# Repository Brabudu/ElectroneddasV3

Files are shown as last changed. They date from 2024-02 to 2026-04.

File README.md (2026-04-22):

# ELECTRONEDDAS V3.0

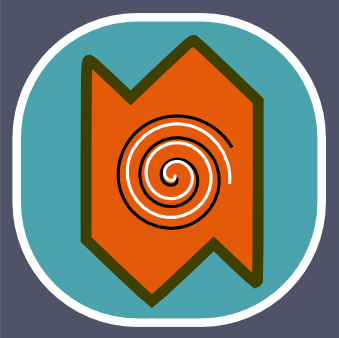
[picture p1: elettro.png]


[Il sito pubblico](https://electroneddas.altervista.org)

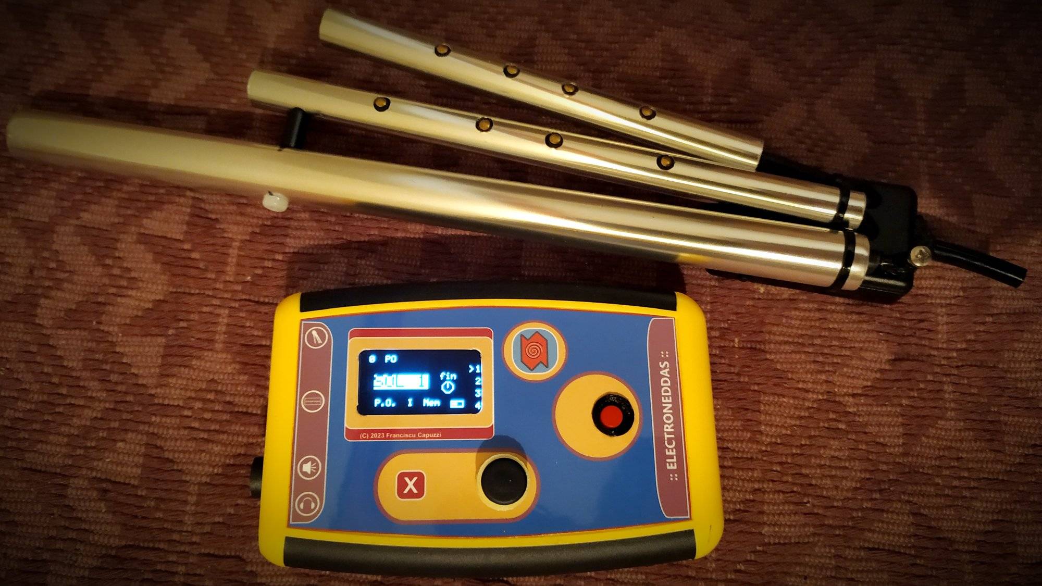
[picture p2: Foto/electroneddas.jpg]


Il terzo modello delle Electroneddas è opensource!

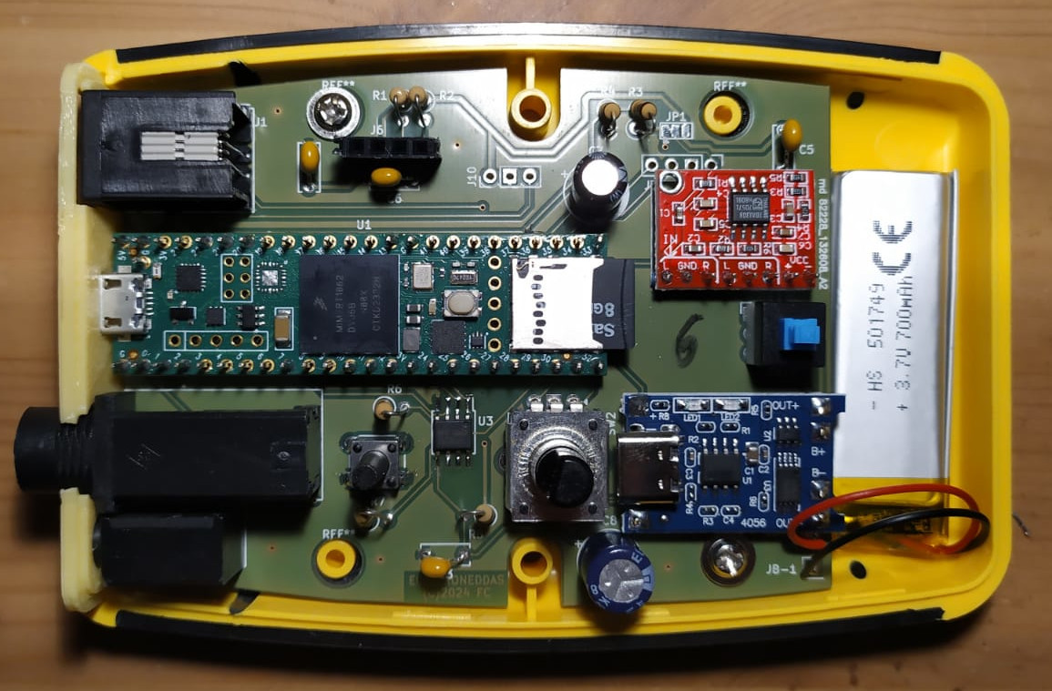
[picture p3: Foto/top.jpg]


## Teensy_Electroneddas:
  Contiene il codice da caricare sul Teensy 4.1 (modalità 396mhz Usb audio+serial+midi)
  
  La compilazione richiede le librerie ArduinoJson e GiverOled 
  
## Java_Electroneddas:

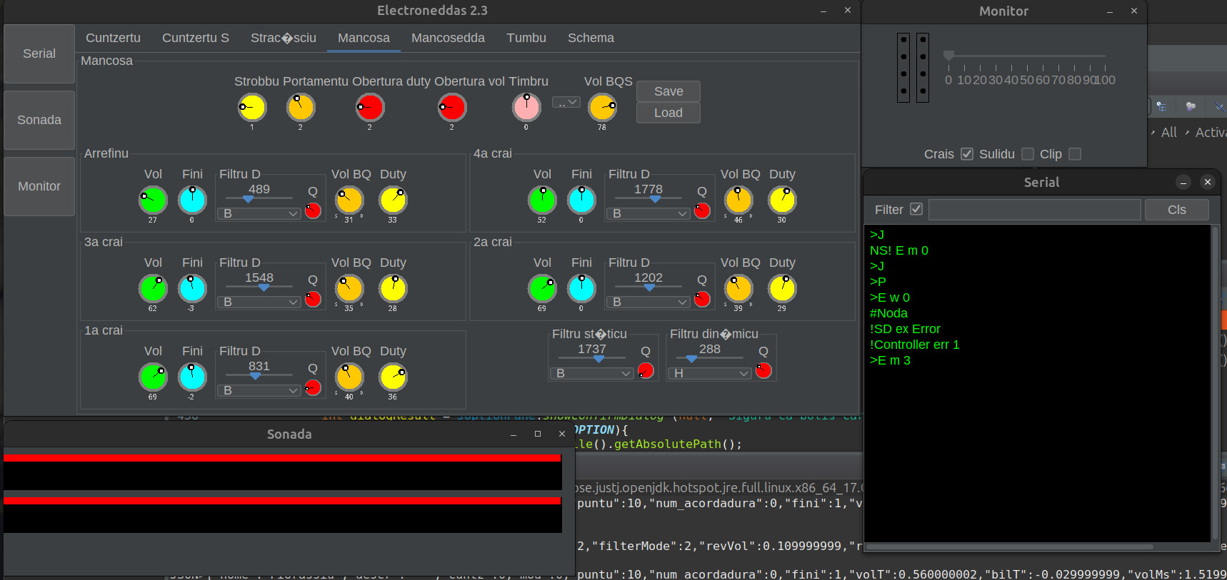
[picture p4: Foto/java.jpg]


  Contiene il codice java per generare il jar dell'applicazione di controllo

## Electronic_Electroneddas:
  Contiene i file kicad con lo schema e il pcb del sintetizzatore e del controller

## 3D_Electroneddas:

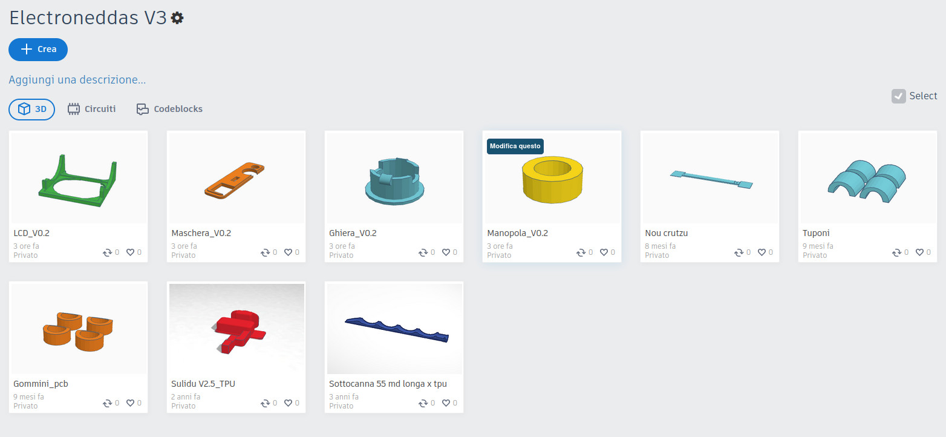
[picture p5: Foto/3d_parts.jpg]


  Contiene i file per le parti da stampare in 3d

## Microchip_Electroneddas:
  Contiene i file per la programmazione del PIC del controller

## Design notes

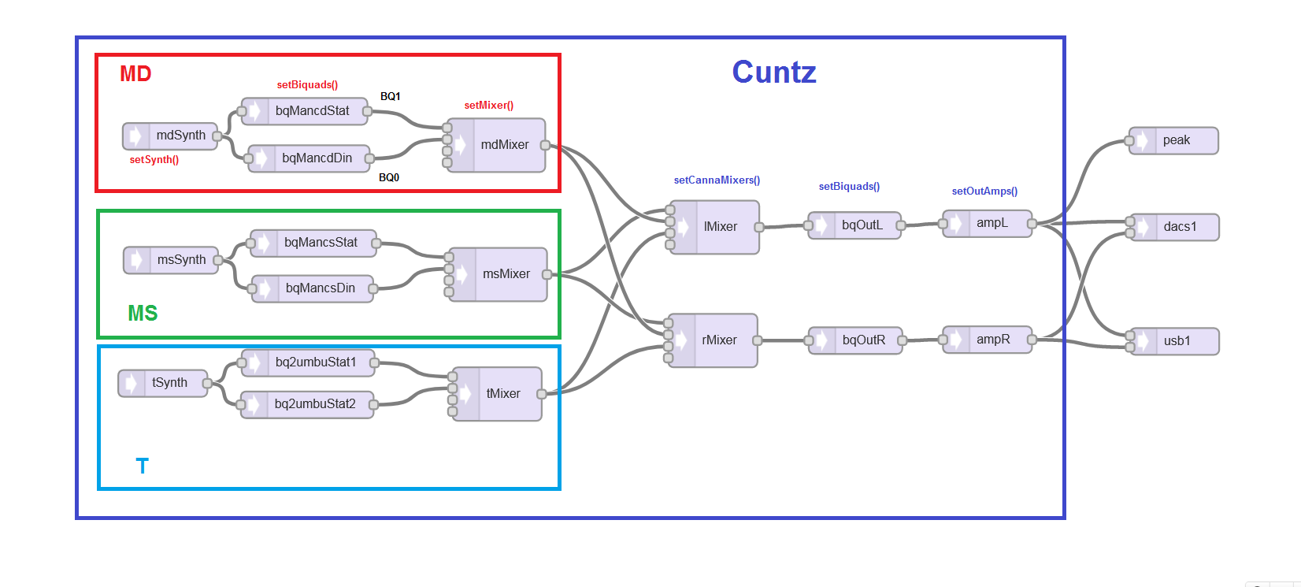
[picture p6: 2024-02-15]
Java_Electroneddas/Electroneddas/src/img/Schema4b.png

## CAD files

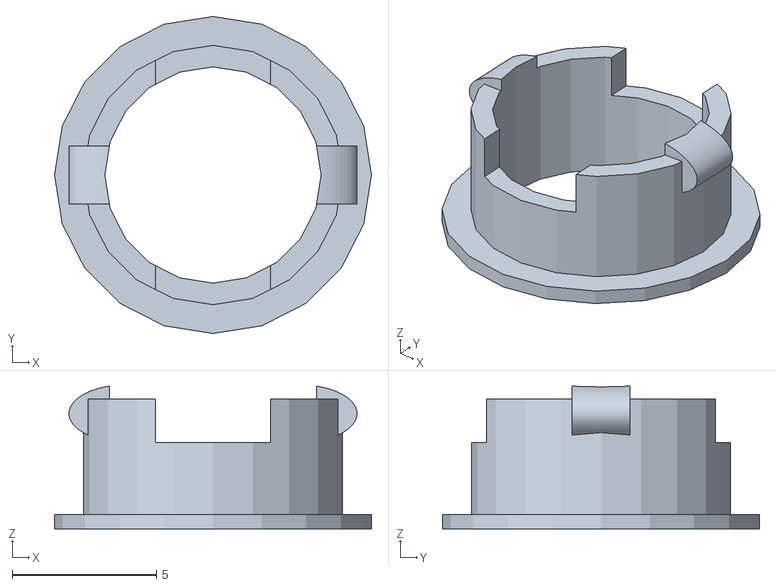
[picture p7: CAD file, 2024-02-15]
3D_Electroneddas/Synth/Ghiera_V0.2.stl
11.0 x 11.0 x 4.95

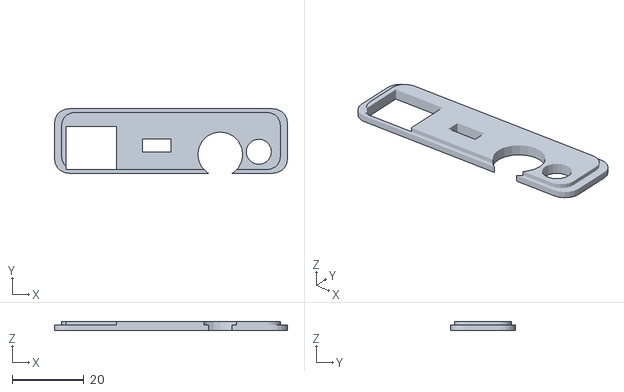
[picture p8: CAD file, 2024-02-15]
3D_Electroneddas/Synth/Maschera_V0.2.stl
65.0 x 18.0 x 2.60

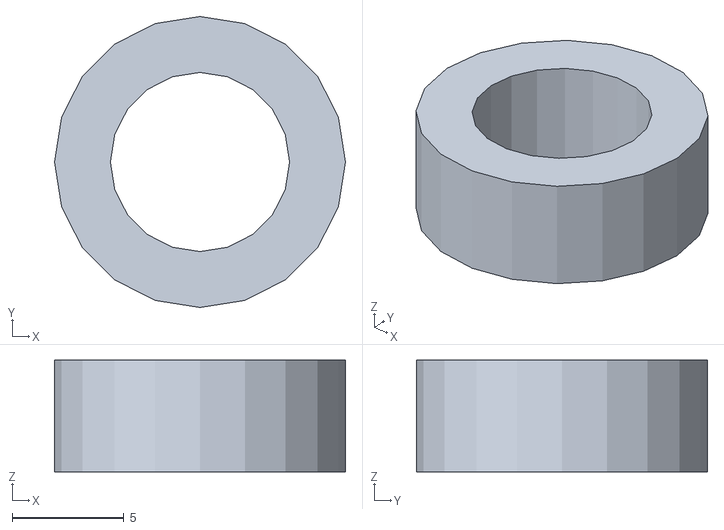
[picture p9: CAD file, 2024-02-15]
3D_Electroneddas/Synth/Manopola_V0.2.stl
13.0 x 13.0 x 5.00

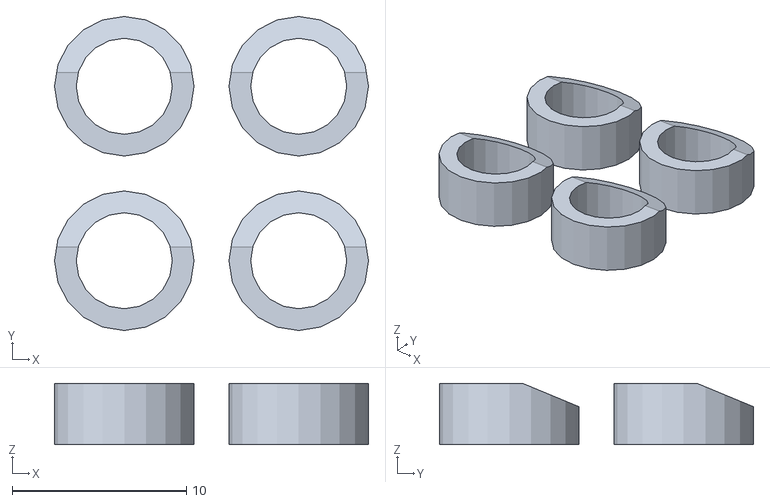
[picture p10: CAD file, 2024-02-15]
3D_Electroneddas/Synth/Gommini_pcb.stl
18.0 x 18.0 x 3.50

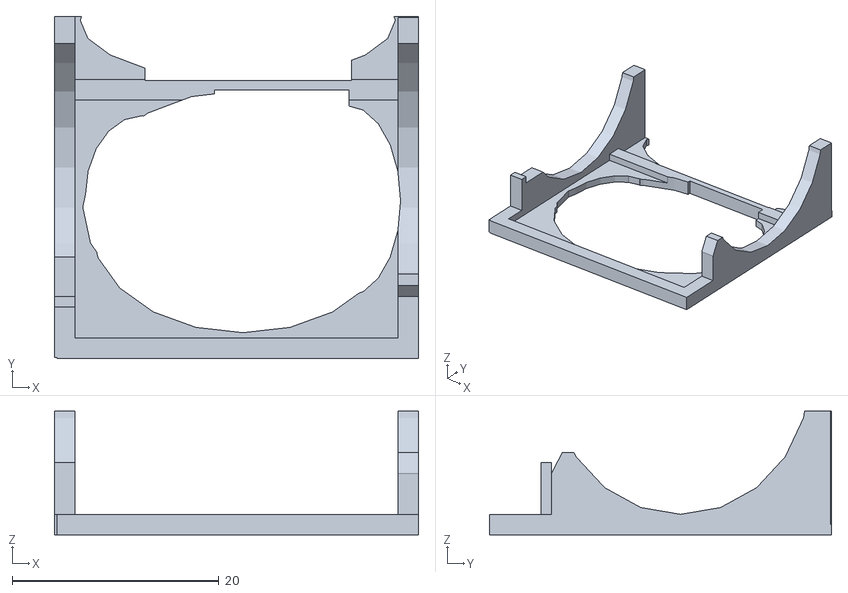
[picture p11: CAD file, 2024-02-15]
3D_Electroneddas/Synth/LCD_V0.2.stl
35.2 x 33.1 x 12.0

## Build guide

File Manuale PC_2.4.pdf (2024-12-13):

Manuale applicazione PC, V2.4

# Pagina iniziale

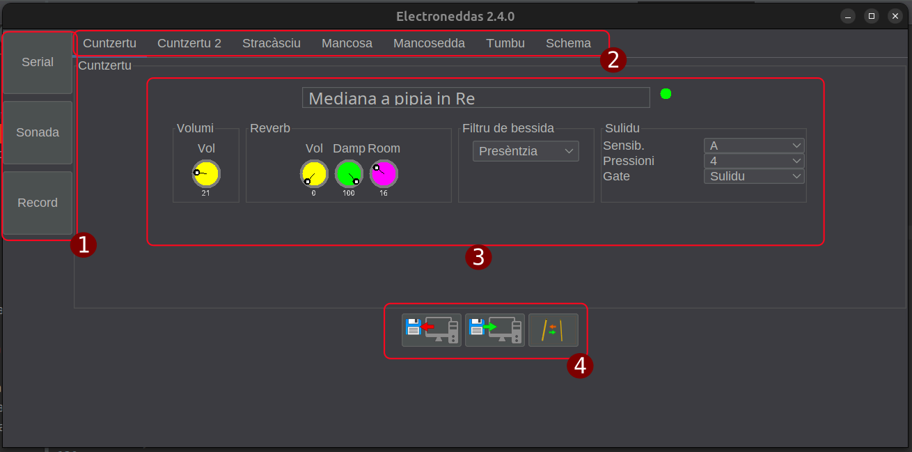
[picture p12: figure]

# ① Bottoni per finestre secondarie

### Ogni bottone fa apparire una finestra secondaria. Le finestre sono descritte più

avanti.

Serial: Visualizza la comunicazione fra PC e electroneddas

Sonada: Visualizza la finestra con la suonata in tempo reale

Record: Visualizza la finestra relativa alla registrazione

# ② Selezione del pannello di lavoro

Cliccando su un bottone viene visualizzata una scheda nella zona ③.

Ogni scheda viene descritta in seguito nel presente manuale.

Cuntzertu: Gestisce le impostazioni generali

Cuntzertu 2: Gestisce le impostazioni relative al cuntzertu attualmente in uso

Stracàsciu: Gestisce is stracàscius dello strumento

Mancosa - Mancosedda - Tumbu : Visualizza le impostazioni della canna

Schema: Visualizza lo schema generale dello strumento

# ③ Pannello di lavoro ④ Operazioni sul cuntzertu

1) Salva cuntzertu: Salva su PC il cuntzertu attuale (* spesso è più utile salvare tutto lo

stracàsciu, vedi oltre)
2) Carica cuntzertu: Carica dal PC il cuntzertu attuale (* meglio lavorare sullo stracàsciu,

vedi oltre)
3) Scambia canne: Scambia le impostazioni relative a timbro e accordatura di mancosa e

mancosedda.
NB! Le canne vengono scambiate completamente solo se è selezionato il tipo di cuntzertu “Personali” (vedi “Cuntzertu 2”). In caso contrario le note delle canne rimangono quelle relative al cuntzertu attuale e non vengono scambiate.

# Cuntzertu

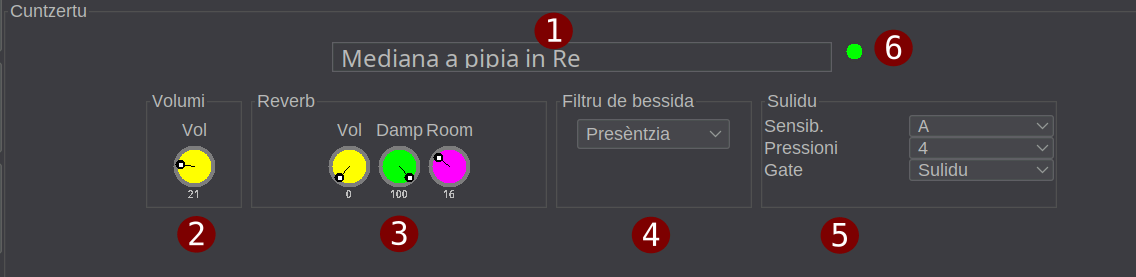
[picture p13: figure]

Questo pannello contiene delle impostazioni raggiungibili anche tramite il display delle electroneddas:

# ① Nome cuntzertu ② Volume generale ③ Effetto riverbero ④ Filtro di uscita ⑤ Impostazioni fiato ⑥ Spia di clipping

Se il monitoraggio del clipping è attivo (vedi “Sonada”), la spia diventa rossa quando i volumi delle canne superano il valore massimo gestibile dallo strumento col pericolo di produrre un suono distorto.
In tal caso conviene abbassare leggermente i volumi delle canne e salvare nuovamente su cuntzertu

# Cuntzertu 2

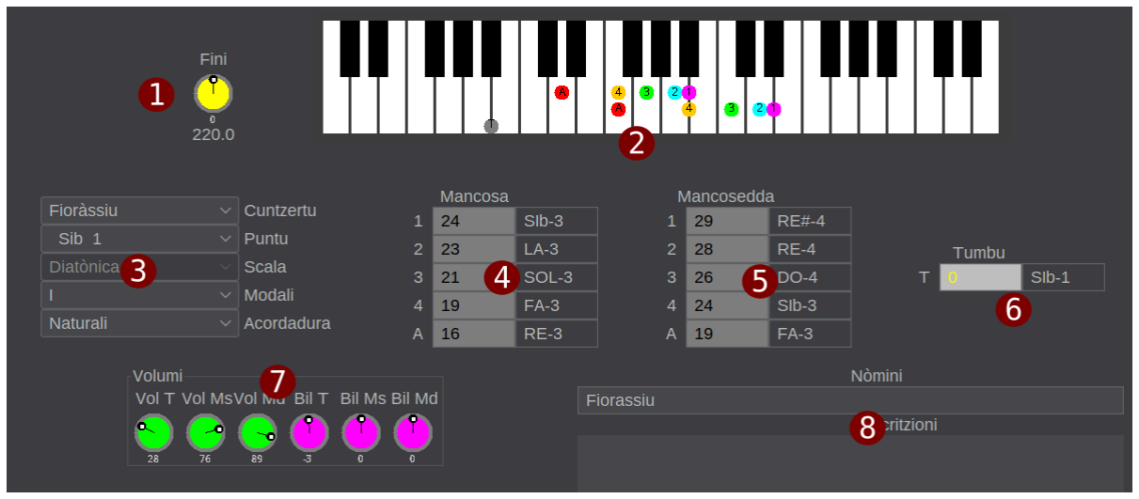
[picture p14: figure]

# ① Accordatura fine dello strumento ② Disposizione de is crais (sola lettura)

Il pannello mostra quali sarebbero le note del tumbu (La T in basso), della mancosa (in alto) e

della mancosedda (a metà) sulla tastiera del pianoforte.

# ③ Impostazioni generali dello strumento

Cuntzertu: Il menu a tendina permette di scegliere un tipo di cuntzertu esistente oppure

di crearne uno personalizzato (selezionando *personali, vedi 4 e 5)
Puntu: Permette di scegliere la tonalità dello strumento

Scala: Permette di scegliere su quale scala viene costruito lo strumento

Modali: Permette di scegliere il grado della scala su cui viene costruito lo strumento. Gli

strumenti tradizionali in genere utilizzano il primo grado della scala (I)
Acordadura: Imposta l’accordatura generale de is crais de su cuntzertu. La nota finale

de is crais dipenderà anche dall’accordatura fine dello strumento e delle singole crais

# ④ ⑤ ⑥ Note di mancosa, mancosedda e tumbu

Le tabelle mostrano il numero di semitoni a partire dalla tonalità di base dello strumento. I valori non possono essere modificati a meno che non sia stato selezionato lo strumento *personali (vedi 3-Cuntzertu)

# ⑦ Pannello volume e bilanciamento

Le manopole verdi permettono di modificare il volume delle tre canne, mentre quelle magenta permettono di spostare il suono della canna verso il canale destro o sinistro (solo per l’uscita stereofonica)

# ⑧ Nome e descrizione strumento

Qui è possibile modificare il nome e la descrizione de su cuntzertu che poi appariranno nel display o nel pannello de su stracàsciu

# Stracàsciu

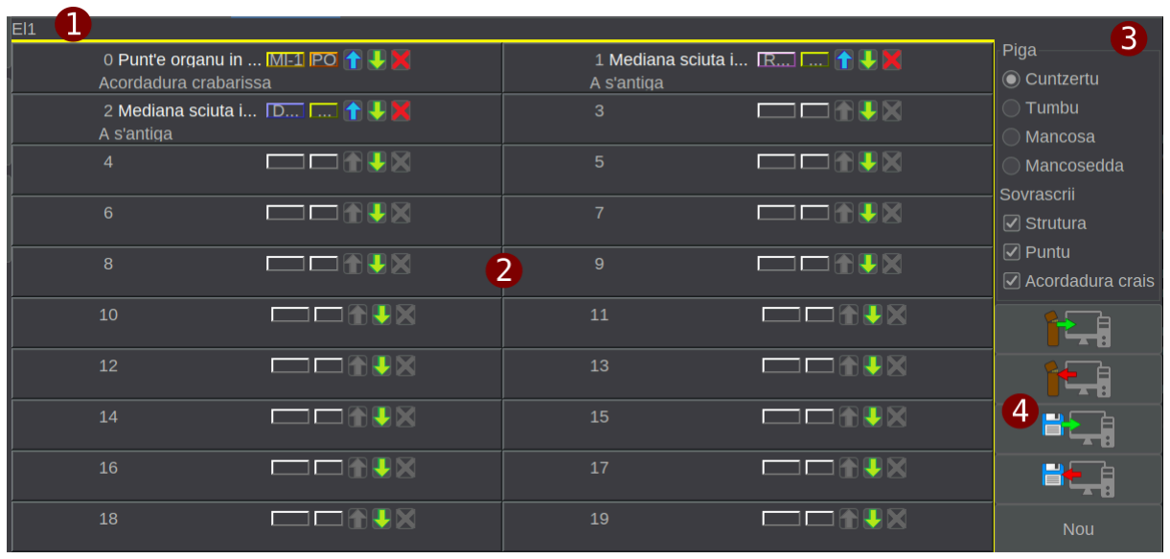
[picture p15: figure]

Su stracàsciu rappresenta un gruppo di strumenti su cui lavorare.
Unu stracàsciu può contenere al massimo 20 strumenti.

### Tale stracàsciu è memorizzato temporaneamente nel PC, per cui la memoria dello strumento non viene modificata a meno che lo stracàsciu non venga poi salvato

nelle electroneddas (vedi oltre).

### Lo stracàsciu di appartenenza di uno strumento memorizzato nelle electroneddas dipende dal suo numero. I primi 20 strumenti (da 0 a 19) apparteranno allo

stracàsciu 0, quelli da 20 a 39 allo stracàsciu 1 e così via.

# ① Nome de su stracàsciu

Se su stracàsciu è stato caricato dalle elettroneddas avrà un nome del tipo El* in cui * indica il numero dello stracàsciu. El0 ad esempio sarà lo stracàsciu di base con gli strumenti dal numero 0 al numero 19, El1 il secondo sctracàsciu con strumenti dal 20 al 39 etc.
Gli stracàsciu caricati dal disco prenderanno invece il nome del file corrispondente

# ② Pannello de is cuntzertus

Ogni riga rappresenta unu cuntzertu. La riga è spiegata nel dettaglio più avanti.

NB Se lo stracàsciu proviene dalle electroneddas, il numero effettivo de su cuntzertu dipende dal numero dello stracàsciu attuale

# ③ Opzioni

Piga: Permette di scegliere se l’operazione piga prenderà interamente o solo in parte unu

cuntzertu dallo stracàsciu (per l’operazione piga (prendi) vedi oltre)
Cuntzertu prende tutto lo strumento, tumbu solo il tumbu e così via.
NB a meno che il cuntzertu non sia di tipo “personali”, le note delle canne rimarranno bloccate al tipo di cuntzertu attualmente in uso, ma verranno prese solo le accordature fini, i volumi, i filtri etc.
Sovrascrii: Permette di scegliere se l’operazione poni salverà interamente lo strumento

nello stracàsciu oppure solo parzialmente:
Strutura: sovrascrive anche le note de is crais dello strumento
Puntu: sovrascrive anche l’intonazione dello strumento
Acordadura de is crais: sovrascrive anche l’intonazione fine de is crais dello strumento
Scala: Permette di scegliere su quale scala viene costruito lo strumento

Modali: Permette di scegliere il grado della scala su cui viene costruito lo strumento. Gli

strumenti tradizionali in genere utilizzano il primo grado della scala (I)
Acordadura: Imposta l’accordatura generale de is crais de su cuntzertu. La nota finale

de is crais dipenderà anche dall’accordatura fine dello strumento e delle singole crais

# ④ Operazioni sullo stracàsciu

Carica unu stracàsciu dalle electroneddas

Salva unu stracàsciu nelle electroneddas

Carica unu stracàsciu dal PC

Salva unu stracàsciu dalle electroneddas

Cancella lo stracàsciu e ne crea unu vuoto

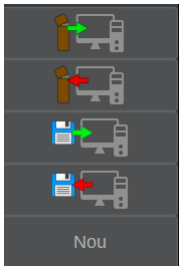
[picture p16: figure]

## NB Solo l’operazione “Salva nelle electroneddas” modifica la memoria dello strumento

# Operazioni su unp strumento de su stracàsciu

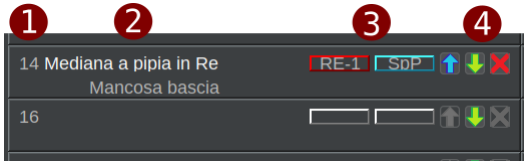
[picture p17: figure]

# ① Numero progressivo dello strumento de su

### stracàsciu (Sola lettura)

# ② Nome e descrizione dello strumento (Sola lettura)

# ③ Tonalità e tipo di cuntzertu dello strumento (Sola

### lettura)

# ④ Operazioni sullo strumento:

Piga (prendi, freccia azzurra) : Prende lo strumento (es. 14) de su stracàsciu. Tale strumento diventa quello correntemente in uso nelle electroneddas, a meno che non si sia fatta una scelta diversa nel riquadro “Piga” (Vedi Opzioni nel paragrafo precedente)

Poni (metti, freccia verde) : Mette lo correntemente in uso nello strumento (es. 14) de su stracàsciu., a meno che non si sia fatta una scelta diversa nel riquadro “Sovrascrii” (Vedi Opzioni nel paragrafo precedente).

Boga (togli, croce rossa): Svuota la riga de su stracàsciu
Es: lo strumento 16 della figura è vuoto

# Mancosa - Mancosedda - Tumbu

## I pannelli “Mancosa” e “Mancosedda” e “Tumbu” permettono di modificare a

fondo il timbro delle canne.
NB Il pannello “tumbu” presenta meno controlli rispetto alle altre canne.

# Caratteristiche generali della canna:

## Strobbu:

Regola la quantità di variazione casuale sulla frequenza della canna. Serve a dare maggior realismo al suono soprattutto in mancanza di modulazione del fiato.

## Portamentu:

Regola la velocità con cui il suono passa da una crai ad un’altra. In altre parole regola l’effetto glissato della canna.

## Obertura duty:

Influisce sul timbro della canna nel caso risulti aperto il tasto subito al di sotto di quello attuale (“crai oberta”). Più precisamente il parametro agisce sul duty cycle dell’onda generata

## Obertura vol:

Influisce sul volume della canna nel caso risulti aperto il tasto subito al di sotto di quello attuale (“crai oberta”).

## Timbru:

Regola collettivamente is crais della canna aprendo o chiudendo il timbro (agisce sul duty cycle dell’onda)

## (Menu a tendina):

Influisce sul timbro della canna scegliendo il tipo di onda generata a monte. (...) P sono onde sintetizzate mentre C sono campionate (utili principalmente po su tumbu)

## Vol BQS:

Influisce sul timbro della canna dando maggior peso al filtro statico o a quello dinamico (vedi sotto).

## Save e load:

Permettono di salvare su file o di caricare da file i dati della canna

## Filtru stàticu:

Imposta le caratteristiche del filtro che viene applicato al suono della canna a prescindere dalla crai suonata (per questo detto statico).

## Filtru dinàmicu:

Il filtro dinamico è composto di due stadi: il primo varia le caratteristiche a seconda del tasto (crai) diteggiato (vedi oltre, Filtro D).
Il secondo stadio, controllato dal riquadro a destra nella figura in alto, è invece unico per tutta la canna.

In qualsiasi tipo di filtro, la sbarra orizzontale indica la frequenza, il menu a tendina il tipo di filtro (L= passa basso, B= passa banda, H= passa alto, l= esalta bassi, h= esalta alti, N= nessun filtro), Q indica il fattore di qualità del filtro, ossia la sua incisività

# Caratteristiche di ogni crai:

## Vol:

Volume relativo de sa crai

## Fini:

Accordatura fine de sa crai

## Filtru D:

Imposta le caratteristiche del primo stadio del filtro dinamico applicato al suono della canna quando risulta aperta tale crai.

## VolBQ

Influisce sul timbro del suono de sa crai dando maggior peso al filtro statico o a quello dinamic).

## Duty

Imposta il duty cycle dell’onda, ossia la larghezza degli impulsi dell’onda rettangolare. In generale un valore basso da un suono più aperto mentre uno alto un suono più chiuso.
Il controllo è ininfluente quando si imposta una forma d’onda campionata (vedi sopra, “menu a tendina”)

# Sonada

# Spartito

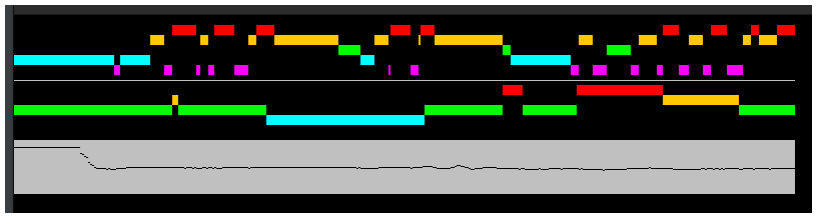
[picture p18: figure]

Questa parte della finestra mostra una trascrizione dinamica dei segnali che arrivano dalle electroneddas.
La parte superiore rappresenta la mancosedda, quella centrale la mancosa e quella inferiore il fiato. (NB I segnali devono essere attivi, vedi sotto)

Cliccando su quest’area della finestra si cambierà la modalità di visualizzazione, a rotazione fra le tre disponibili.

# Situazione sensori

Questa parte visualizza in tempo reale lo stato dei sensori di mancosa e mancosedda. Il foro è giallo se il sensore rileva la presenza del dito. (NB I segnali de is crais devono essere attivi, vedi sotto)

Questa parte visualizza in tempo reale lo stato del sensore di pressione del fiato.
(NB Il segnale de su sulidu deve essere attivo)

# Acquisizione segnali sensori

La casella selezionata indica che il segnale proveniente dalle electroneddas verrà rilevato dal programma. Crais indica i segnali relativi ai tasti, Sulidu al fiato e Clip al raggiungimento del livello di clipping (vedi pannello principale)

# Registrazione su file

Tramite il pulsante indicato tutti i segnali provenienti da is crais verranno salvati su file per potere essere elaborati in seguito per usi particolari. Il programma chiederà di selezionare il nome e la posizione del file e comincerà ad acquisire i dati. L’acquisizione terminerà alla pressione del tasto stop.

# Record

Tramite questo pannello è possibile registrare una sonada per poterla riascoltare in seguito.

# Registrazione e riproduzione

Il tasto Rec avvierà la registrazione, che partirà e si fermerà in base alla modalità di gate selezionata. La registrazione può essere fermata anche col tasto Stop.

Il tasto Play riprodurrà la registrazione presente in memoria. La riproduzione si fermerà al termine della stessa o con la pressione del tasto Stop.

Ogni registrazione cancellerà la precedente, per cui prima di effettuare una nuova registrazione sarà necessario salvarla in memoria.

# Salvataggio in memoria

Per salvarla in memoria occorrerà selezionare prima di tutto la posizione della memoria che si intende utilizzare (da 0 a 100) ed eventualmente il nome che si intende memorizzare (fino a 32 caratteri).
Premendo il tasto Save la registrazione attuale verrà memorizzata permanentemente nella posizione scelta.

Per caricare dalla memoria una registrazione occorre invece scegliere la posizione che si vuole caricare e poi premere il tasto Load.
Se nella posizione scelta esiste una registrazione, il suo nome apparirà nella casellina. In caso contrario apparirà un messaggio di errore.

# Aggiornamento firmware

L’aggiornamento del firmware, cioè del programma che gestisce internamente le electroneddas, va effettuato tramite sistema PC con sistema operativo Windows:

1. Scaricare il file programmatore***.zip (*** indica la versione del file).
2. Scompattare il contenuto dell’archivio in una cartella
3. Collegare le electroneddas al PC tramite USB
4. Accendere le electroneddas
5. Avviare il file program.bat e seguire le indicazioni sullo schermo

# Aggiornamento software

L’aggiornamento del software di controllo da PC descritto in manuale consiste semplicemente nel sostituire il file Electroneddas.jar con la versione più recente

# Problematiche di connessione

Se il PC non dovesse riconoscere le Electroneddas verificare su “Gestione dispositivi” che appaia qualcosa del genere:

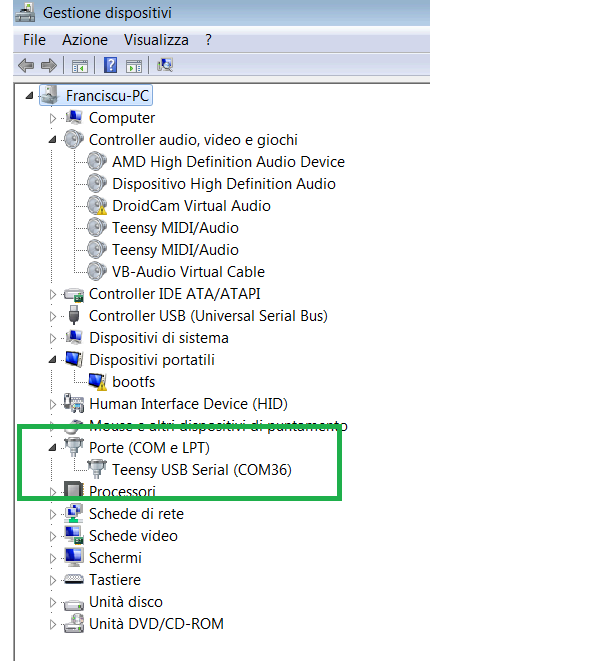
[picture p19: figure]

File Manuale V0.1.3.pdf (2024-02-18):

Le electroneddas

1 sono uno strumento musicale elettronico finalizzato a riprodurre le caratteristiche organologiche dello strumento tradizionale: in altre parole sono costruite in modo che il suonatore possa suonarle con la tecnica il più possibile simile a quella che utilizza sulle launeddas.

# Il controller

Il controller è la parte dello strumento che il suonatore tiene in mano, su cui quindi poggia le dita, e in cui può soffiare per dare espressione alla suonata.
La posizione dei tasti (crais) è fissa, e viene decisa generalmente dal suonatore in base alle proprie preferenze.
I tasti sono del tipo a sfioramento, cioè non richiedono una pressione delle dita, e riconoscono due stati: tasto aperto e tasto chiuso.
Non è quindi possibile effettuare glissati, poiché lo strumento non riconosce l'apertura parziale di un foro.
Il suonatore può soffiare tramite il tubo ①
La vite ② permette di regolare il deflusso di aria; per ottenere un ulteriore deflusso la vite può essere rimossa.

Il pulsante ③ (presente nel nuovo modello) ha due funzioni:

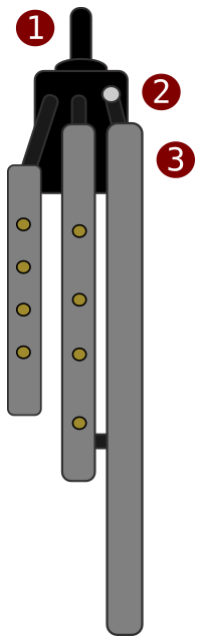
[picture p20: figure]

- Se viene premuto per qualche istante durante la fase di accensione dello strumento, permette di impostare una minore sensibilità dei tasti rispetto al normale
- Mantenendolo premuto durante il normale funzionamento permette di scegliere il cuntzertu precedente o successivo toccando i tasti alti o bassi della mancosa

1
Indifferentemente Eletroneddas (grafia sarda), Elettroneddas (grafia italiana) o Electroneddas

UNA PRESSIONE DI ARIA ECCESSIVA POTREBBE DANNEGGIARE LO STRUMENTO: UTILIZZARE ESCLUSIVAMENTE IL FIATO

La parte relativa al fiato può essere pulita periodicamente inserendo qualche goccia di alcool tramite un contagocce.
I tasti possono essere puliti con un panno asciutto o imbevuto di alcool.

# Il sintetizzatore

Il sintetizzatore contiene i circuiti elettronici che generano il suono e comunica con il controller tramite un cavo (telefonico) e con il PC tramite porta USB. Lo schema sottostante mostra lo schema del cavo.

Il suonatore può scegliere su cuntzertu, la tonalità e tutti gli altri parametri interagendo con il controller tramite lo schermino LCD , la manopola e il tasto presente sul sintetizzatore.

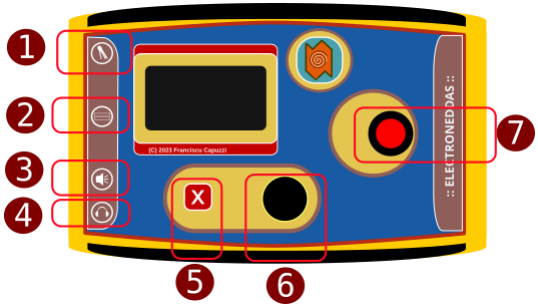
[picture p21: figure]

# ① Ingresso controller (rj 11)

Collegare il controller a strumento spento. Nel caso lo si faccia a strumento acceso, premere ripetutamente il tasto annulla (5) per inizializzare la comunicazione.

# ② Uscita USB / Ricarica (mini usb b)

Utilizzare un cavo mini usb di tipo b per caricare lo strumento e/o comunicare con l’applicazione delle elettroneddas installata su pc o per inviare comandi MIDI al pc

③ Uscita audio (jack 6.3mm mono)

L’uscita è monofonica e non amplificata.

④ Uscita cuffie (jack 3.5mm stereo)

L’uscita è stereofonica e amplificata. Prima di indossare le cuffie controllare che il volume non sia troppo alto

# ⑤ Tasto annulla ⑥ Rotella selezione

Muovendo la rotella si cambia pagina o si controlla il cursore all’interno del display, premendola è possibile selezionare o modificare i parametri (vedi dopo)

# ⑦ Pulsante accensione e spia ricarica

Una luce rossa attorno al pulsante indica che la batteria è in carica, una luce blu che la carica ha raggiunto il massimo

# Pagina 1

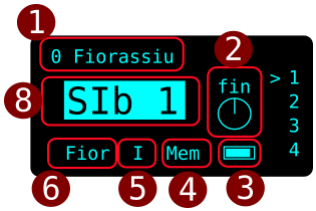
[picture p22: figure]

# ① Strumento selezionato ② Accordatura fine ③ Livello batteria ④ Memorizza strumento

Premendo la rotellina per oltre un secondo vengono memorizzate le regolazioni dello strumento attuale (quelle della pagina 1 e della pagina 2)

# ⑤ Scala modale ⑥ Tipo cuntzertu

# Pagina 2

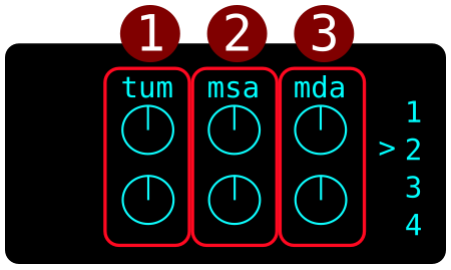
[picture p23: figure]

# ① Volume/bilanciamento tumbu ② Volume/bilanciamento mancosa ③ Volume/bilanciamento mancosedda

NB Il bilanciamento ha effetto solo sull’uscita stereofonica

# Pagina 3

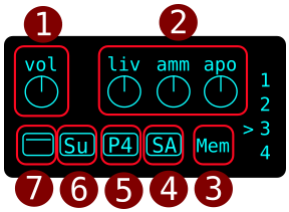
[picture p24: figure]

# ① Volume uscita

Regola il volume di uscita dello strumento. Un valore troppo alto potrebbe dare distorsione

### ② Riverbero: livello, attenuazione, stanza

Il livello (liv) regola la quantità di riverbero rispetto al suono pulito, attenuazione (amm) l’effetto sulle alte frequenze (damping) mentre stanza (apo) indica la dimensione della stanza simulata

# ③ Memorizza

Premendo la rotellina per oltre un secondo vengono memorizzate le regolazioni di questa pagina

# ④ Sensibilità fiato

Tre livelli: Alta (SA), media (SM) e bassa (SB)

# ⑤ Pressione fiato

Cinque livelli: da P0 (bassa) fino a P5 (alta)

# ⑥ Modalità attivazione

No: suono sempre attivo
Cr: il suono rimane finchè risulta chiuso almeno un foro
Su: il suono rimane finchè è presente una pressione del fiato
AS: il suono si attiva e si disattiva dando un leggero colpo di fiato
CS: modalità Cr e Su combinate ma separate per mancosa e mancosedda

# ⑦ Filtro uscita

￣￣ : nessun filtro
￣\ : attenua le frequenze alte _/￣ : esalta le frequenze alte

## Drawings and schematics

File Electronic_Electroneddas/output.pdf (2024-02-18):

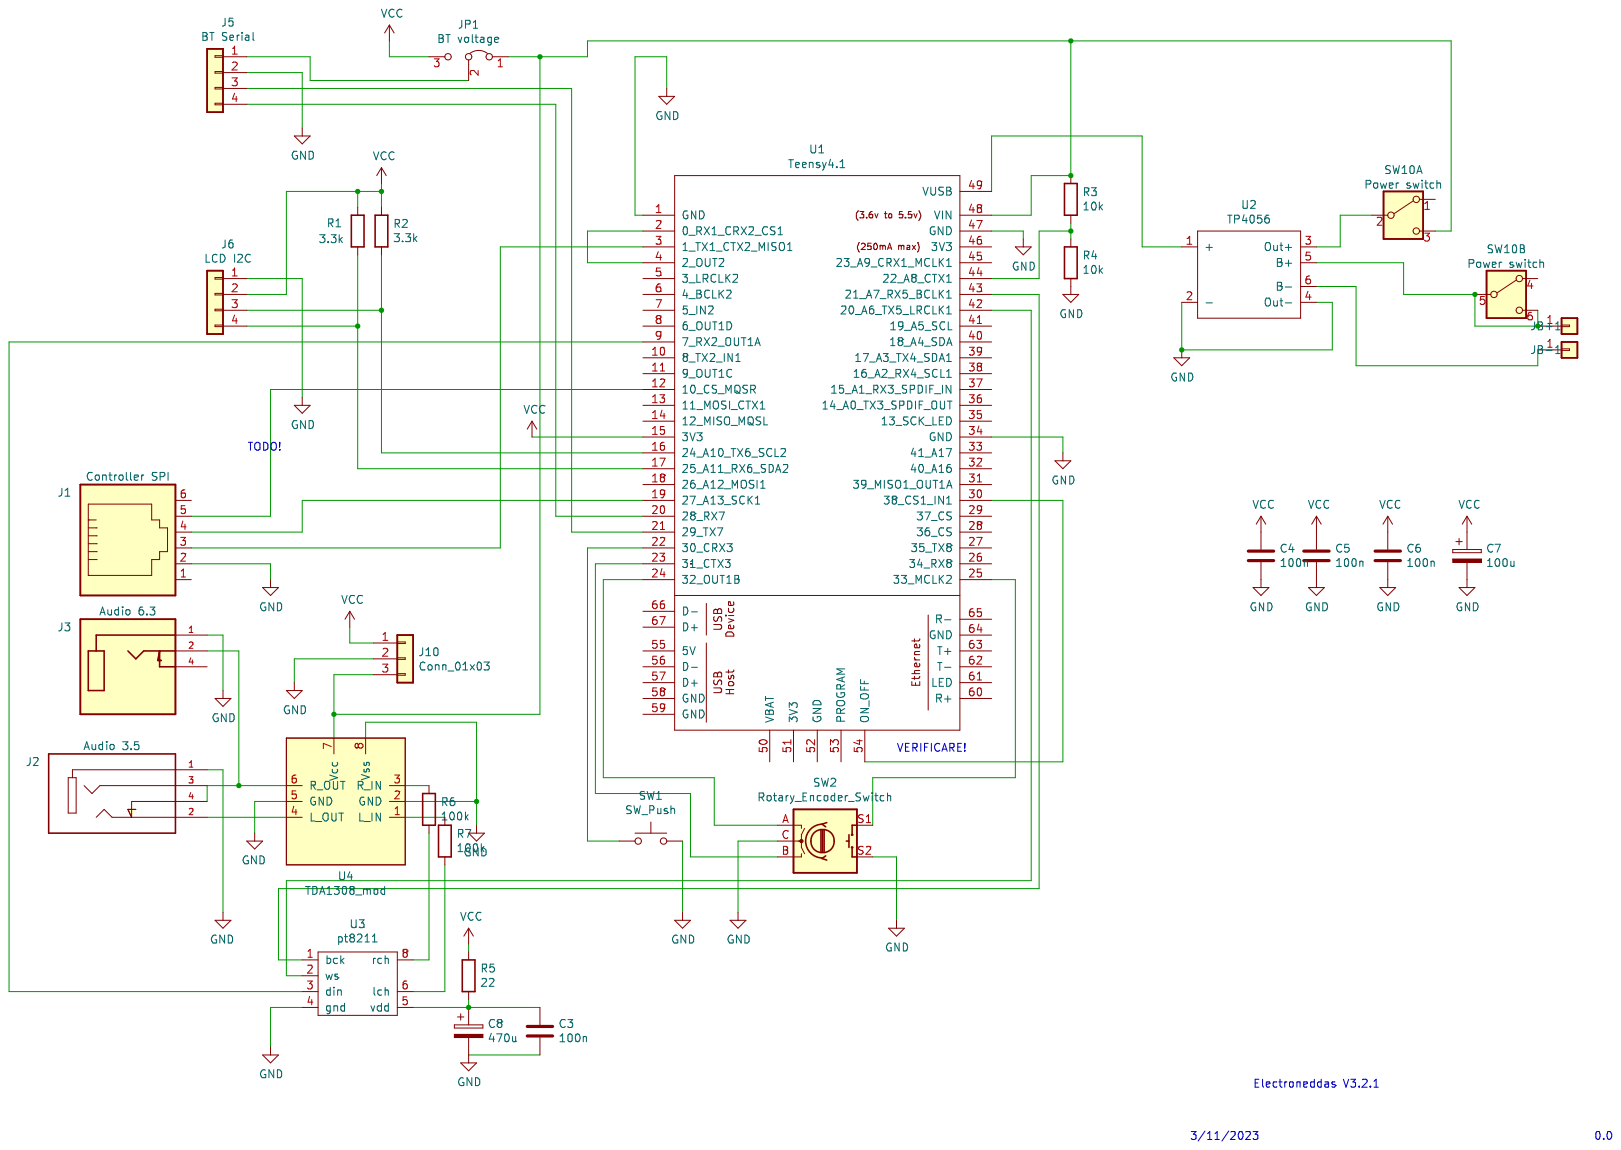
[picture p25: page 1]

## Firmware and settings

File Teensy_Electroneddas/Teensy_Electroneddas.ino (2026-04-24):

/*
Required libraries: 

ArduinoJSON 
  https://arduinojson.org/

GyverOLED
  https://github.com/GyverLibs/GyverOLED


*/

#include <Audio.h>
#include <SPI.h>
#include <ArduinoJson.h>
#include <EEPROM.h>
#include <SerialFlash.h>


#include "Cannas.h"
#include "Display.h"
#include "ElFileSystem.h"

#include "Recorder.h"

#ifndef functions_h
  #include "functions.h"
#endif

#ifndef info_h
  #include "info.h"
#endif

#include "Communicator.h"

#include "2SPISlave_T4/2SPISlave_T4.h"

#include <Entropy.h>

#include "sdios.h"

#define version "2.5.0"

//2.2   12/01/2024  

/*16/4/21
  */

//2.3.1 10/3/24 note negative

//2.3.1 4/4/24 transp midi

const char json[] = "{\"nome\":\"PO\",\"descr\":\"Sol\",\"vol\":0.5,\"cuntz\":1,\"mod\":0,\"puntu\":7,\"fini\":1.0,\"volT\":0.62,\"bilT\":-0.03,\"volMs\":0.98,\"bilMs\":0.0,\"volMd\":1.16,\"bilMd\":0.0,\"bq\":{\"freq\":0,\"q\":0.0,\"type\":\"N\"},\"tumbu\":{\"volArm\":0.9,\"strb\":6,\"sonu\":4,\"port\":10,\"bqStat\":{\"freq\":169,\"q\":1.678804,\"type\":\"H\"},\"bqDinF\":{\"freq\":0,\"q\":0.0,\"type\":\"N\"},\"crais\":[{\"vol\":1.0,\"volA\":1.0,\"fini\":1.0,\"duty\":0.05,\"puntu\":0,\"bq\":{\"freq\":301,\"q\":1.0,\"type\":\"N\"}}]},\"mancs\":{\"volArm\":1.56,\"strb\":2,\"sonu\":1,\"port\":10,\"bqStat\":{\"freq\":2089,\"q\":0.34673685,\"type\":\"B\"},\"bqDinF\":{\"freq\":1148,\"q\":0.3019952,\"type\":\"B\"},\"crais\":[{\"vol\":0.39,\"volA\":2.28,\"fini\":1.0,\"duty\":0.33,\"puntu\":7,\"bq\":{\"freq\":549,\"q\":1.0,\"type\":\"B\"}},{\"vol\":0.52,\"volA\":1.84,\"fini\":1.0,\"duty\":0.3,\"puntu\":9,\"bq\":{\"freq\":2137,\"q\":1.0,\"type\":\"B\"}},{\"vol\":0.62,\"volA\":1.4,\"fini\":0.9928057,\"duty\":0.28,\"puntu\":11,\"bq\":{\"freq\":1737,\"q\":1.0,\"type\":\"B\"}},{\"vol\":0.69,\"volA\":1.56,\"fini\":1.0,\"duty\":0.28,\"puntu\":12,\"bq\":{\"freq\":1348,\"q\":1.0,\"type\":\"B\"}},{\"vol\":0.69,\"volA\":1.6,\"fini\":0.99639636,\"duty\":0.33,\"puntu\":14,\"bq\":{\"freq\":933,\"q\":0.52480745,\"type\":\"B\"}}]},\"mancd\":{\"volArm\":1.62,\"strb\":5,\"sonu\":1,\"port\":10,\"bqStat\":{\"freq\":2089,\"q\":0.4365158,\"type\":\"B\"},\"bqDinF\":{\"freq\":1778,\"q\":1.0,\"type\":\"B\"},\"crais\":[{\"vol\":0.52,\"volA\":2.44,\"fini\":1.0,\"duty\":0.34,\"puntu\":12,\"bq\":{\"freq\":630,\"q\":1.0,\"type\":\"B\"}},{\"vol\":0.56,\"volA\":2.72,\"fini\":0.99639636,\"duty\":0.3,\"puntu\":14,\"bq\":{\"freq\":2238,\"q\":1.0,\"type\":\"B\"}},{\"vol\":0.64,\"volA\":1.32,\"fini\":1.0,\"duty\":0.24,\"puntu\":16,\"bq\":{\"freq\":1659,\"q\":0.91201085,\"type\":\"B\"}},{\"vol\":0.63,\"volA\":1.24,\"fini\":1.0036167,\"duty\":0.26,\"puntu\":17,\"bq\":{\"freq\":1584,\"q\":0.45708817,\"type\":\"B\"}},{\"vol\":0.65,\"volA\":1.56,\"fini\":1.0,\"duty\":0.35,\"puntu\":19,\"bq\":{\"freq\":1122,\"q\":0.44157046,\"type\":\"B\"}}]}}";



//Schema V1.0

#include "schema.h"

extern "C" uint32_t set_arm_clock(uint32_t frequency);

#define HI_SPEED  600000000
#define LOW_SPEED  150000000

////// HARDWARE //////////////////////

#define CS_CON  2     //SPI CS
#define OFF_CON  38   //Todo

#define V_CONTR  10   //SPI Vcc

#define BLUETOOTH Serial7

#define MIDI_IN_CHAN 0


SPISlave_T4 <&SPI1, SPI_8_BITS> mySPI; 
;
////
volatile uint8_t lt_pkt[6]; // Buffer ricezione
volatile uint8_t lt_pr = 0; //
volatile uint8_t lt_pp = 0; //


uint8_t last_error = 0;
uint8_t last_error_mem = 0;



volatile long inact_timer = 0; //


////
float old_sul=0;
int sul_count=0;

//byte oldcrai[2];

////// gestione console //////
char ser_buffer[3000];
int ser_b_index = 0;

String command="";

//////
//Battery
  #define BATT  A8   //Todo
    float charge=4.2;
////// gestione Bluetooth //////
#define MAX_BT_BUFF 128
char cstring1[MAX_BT_BUFF];  //!!!!!!!!!!!!!!!!!!!!!!!!
//byte addbuffer[64];
int cindex1 = 0;
bool cpronto1 = false;

bool bt_controller = false;
bool bt_control = false;

const bool BT_CRLF = true;
//////

//Gestione monitor
#define CRAIS 1
#define ESA   2
#define SUL   4
#define BT    8
#define CLIP  16

int mon_mode=0;

//byte act_file=0; // Caricamento cuntzertu

// Timer monitor (clip)
IntervalTimer monitorTimer;

uint8_t cuntz_num=0;
#define MAX_CUNTZ_NUM 200

// Pedaliera
#define STRAC 0
#define CROMA 1
#define CONTROL 2
#define TUMBU_F  3
#define TUMBU_T 4
#define SCRIPT 5

uint8_t ped_mode=0;
uint8_t ped_last=0;
uint8_t ped_strac=0;
///EEPROM

#define EEPROM_ID 0
#define EEPROM_HW 1

#define HW_BT 0xaa


Cuntzertu* c; 

Display* d;

ElFileSystem* efs;

Communicator* com;

Recorder* rec;

void setup() {

  // Pulsantis e led
  pinMode(PIN_PULS_OK, INPUT_PULLUP);
  pinMode(PIN_PULS_CANC, INPUT_PULLUP);

  pinMode(OFF_CON, OUTPUT);
  digitalWrite(OFF_CON, HIGH);

  pinMode(V_CONTR, OUTPUT);
  
  
  pinMode(LED_BUILTIN, OUTPUT);
  
  // SPI slave
  pinMode(CS_CON, OUTPUT); //CS
  digitalWrite(CS_CON, LOW);

  AudioMemory(20);
  Entropy.Initialize();

  Serial.begin(115200);   //USB
  
  set_arm_clock(LOW_SPEED);

  com=new Communicator(&Serial);

  //Bluetooth
  BLUETOOTH.begin(9600);    //BTooth

  if (EEPROM.read(EEPROM_HW) == HW_BT) {
    bt_control=true;
  }
  
  //BLUETOOTH.addMemoryForRead(addbuffer,64);  // Per comunicare con la app

  digitalWrite(V_CONTR, HIGH);
  delay(100);
  digitalWrite(CS_CON,HIGH);
  
  delay(100);
 
  lMixer.gain(3,0.3);
  rMixer.gain(3,0.3);

  //mdMixer.gain(2,0.7);  //TEST
  //ldMancd.frequency(500);
  //ldMancd.resonance(1);
   
  mySPI.onReceive(receiving);
  mySPI.begin();

  c=new Cuntzertu();

  d=new Display(bt_control);

  efs=new ElFileSystem();
  
  if (!efs->isMounted()) {
        com->msgError("SD Error");
        d->showLogo("SD ERR");
    } else {
        d->showLogo(version);
    }
  initCuntz();
 
  monitorTimer.begin(monitoring, 200000);
  monitorTimer.priority(255);
  
  digitalWrite(V_CONTR, HIGH);

  delay(500);
  digitalWrite(CS_CON,LOW);
  
  if (digitalRead(PIN_PULS_OK)==false) d->test();
  else d->initMenu();

  rec=new Recorder();

   usbMIDI.setHandleProgramChange(myProgramChange);

}

void loop() {

  if (!rec->isPlaying()) {
  
    //USB Serial
    pollSerial();
    
    //BT Serial
    pollBT();
    
    //SPI
    pollSPI();

    pollMIDI();
    

    if (command.length()>0) {
      parse(command);
      command="";
    }
  } else {
    uint8_t s;
    if ((s=rec->getSample())!=0) {
      sona(s);
    }
    //USB Serial
    pollSerial();
  }
}

void pollSerial() {
   while (Serial.available() > 0) 
  {
    inact_timer = 0;
    
    char byteBuffer = Serial.read();  
    ser_buffer[ser_b_index++] = byteBuffer;

    if (ser_b_index>=3000) {
      com->msgError("Serial buffer full");
      ser_b_index=0;
    }
    
    if (byteBuffer == 10)
    {
      ser_buffer[--ser_b_index] = 0;        
      parse(ser_buffer);  //Generali
      
      ser_b_index = 0;
    }
  }
}

void pollSPI() {
    if (lt_pr != lt_pp) {
      inact_timer = 0;
      
      lt_pp++;
      uint8_t b = lt_pkt[lt_pp % 6];
    sona(b);
 
  } 

}
void pollBT() {
 
  if (bt_control) {
  //Bluetooth
    while ((BLUETOOTH.available() > 0) && (!cpronto1))
    {
      char byteBuffer = BLUETOOTH.read();
    
      if (!((cindex1==0)&&((byteBuffer==' ')||(byteBuffer==0)))) { //trim   
         
        cstring1[cindex1++] = byteBuffer;
        if ((byteBuffer == 10)||(cindex1>=MAX_BT_BUFF))
        {
          cstring1[--cindex1] = 0;
  
          if ((mon_mode&BT)||bt_controller) {     
            com->msgInfo("BT> ",cstring1);
          }
          
          if (!bt_controller)  parse(cstring1);  //Generali
       
          cindex1 = 0;
          cpronto1 = false;
        }
      }
    }
  }
}
void pollMIDI() {
  while(usbMIDI.read()){}
}
void sona(uint8_t b) {  

      //Sulidu
      if (b>=128 ) {
        b&=0x7F;
        float sul=(float)b;
      
        if (sul!=old_sul) {
          c->setSul(b);   
          if (rec->isRecording()) rec->putSample(b|0x80); 
          if (mon_mode&SUL) {
            com->msgWarning('s'+String(b),true);
          }
          old_sul=b;
        }
        return;
      }

      //Crais & msg
      if (rec->isRecording()) rec->putSample(b);
      uint8_t canna = 0;
      uint8_t nota = 0;

      uint8_t hi_nibb=b&0xf0;
      uint8_t lo_nibb=b&0x0f;

      if (hi_nibb==0x70) { //Comando da controller
        int dir=0;
        if (lo_nibb==0) return;
        if (b&0x1) dir=1;
        if (b&0x8) dir=-1;

        if (!efs->isMounted()) return;
        do {
          cuntz_num=(cuntz_num+dir+MAX_CUNTZ_NUM)%MAX_CUNTZ_NUM;
        } while (!efs->cuntzFromFileJson(c,cuntz_num,true));
        c->setPreferredCuntz(cuntz_num);
        d->displayPage();
        d->update();
      
      } else {
        nota = byteToCrai(b, &canna);
               
        if (mon_mode&CRAIS)  {
          String can;
         
          if (canna==1) can="S"; 
          else can="D";
          
            String msg=can+":";
            char myHex[2] = "";
   
            if (mon_mode&ESA) ltoa(lo_nibb,myHex,16);
            else ltoa(nota,myHex,16);
            msg+=String(myHex);
            com->msgWarning(msg,true);
              
        }
       
        if (canna == 1) {
          c->mancs.playCrai(nota,lo_nibb);
        }
        if (canna == 2) {
          c->mancd.playCrai(nota,lo_nibb);
        }


        if (canna == 3) {           //Sys msg
          if (b==3) {
            last_error=0;   //Controller prontu (0x33)
            last_error_mem=0;
            com->msgOk("Controller prontu");
          }
          else {
            last_error=1+(b>>1);
            last_error_mem=last_error;
          }
        }
      }
}

void monitoring() {
  if ((mon_mode&CLIP)&&peak.available()) {    
    uint8_t lPeak=peak.read() * 100.0;
    if (lPeak>99) com->msgWarning("CLIP",false);
  }
  
  if (last_error!=0) {
    String msg="Controller err "+String(last_error);
    com->msgError(msg);
    last_error=0;
  }

  //Batteria
  int v=analogRead(BATT);
  float volt=v/155.152; //(v=x/1024*3,3*2);
  charge=(charge+volt)/2; //max=0,7

  d->refreshBattery();
  
  inact_timer++;

  if (inact_timer>2000) {
    //digitalWrite(OFF_CON,LOW);
    //delay(5000);
  }
  
}
float getCharge() {
  return charge;
}
uint8_t byteToCrai(uint8_t b, uint8_t* msg) {

  *msg = ((b >> 4) & 0x3) ^ 3;
  if ((b & 0x80) == 0x80) *msg = 0;

  b = ~b & 0xf;// & ~(c.cannas[*msg - 1].mask & 0xf);

  if (b & 8) return (4);
  if (b & 4) return (3);
  if (b & 2) return (2);
  if (b & 1) return (1);
  return (0);
}



void receiving() {

  if (mySPI.active()) {
    mySPI.pushr(0);
    uint16_t data = mySPI.popr();
    lt_pr++;
    lt_pkt[lt_pr % 6] = (uint8_t)data;    
  }
}
void parse(String s) {
  s.trim();
  if (s.length()==0) return;
  if (s[0]!='E') {
    c->parse(s); //Cuntzertu
  }
  else {
    String sParams[5];
    StringSplit(s, ' ', sParams, 5);
    switch (sParams[1][0]) {
      case 'i':
        com->msgInfo(String("Id :")+EEPROM.read(0));
        com->msgInfo(String("Hw :")+EEPROM.read(1));
        com->msgInfo(String("Version :")+version);
        com->msgInfo(String("Audio memory: ")+AudioMemoryUsageMax());    
        com->msgInfo(String("Audio CPU max: ")+AudioProcessorUsageMax());
        break;
        /* Noise Test
      case 't':
        nMixer.gain(0,sParams[2].toFloat());
        nMixer.gain(1,sParams[3].toFloat());
        break;
      case 'f':
        bqNoise.setHighpass(0,sParams[2].toInt(),1);
        noise1.amplitude(sParams[3].toFloat());
        break;
        */
      case 'I':
        EEPROM.write(EEPROM_ID,sParams[2].toInt()&0xff);
        EEPROM.write(EEPROM_HW,sParams[3].toInt()&0xff);
      break;
      case 'm':
        mon_mode=sParams[2].toInt();
        break;
      case 'B':
        BLUETOOTH.println(sParams[2]);
        BLUETOOTH.flush();
        break;
      case 'b':
        bt_controller=sParams[2].toInt();
        break;
      case 'd':
        efs->listaFiles(false);
        break;
      case 'S':
        set_arm_clock(sParams[2].toInt()*1000000);
        break;
      case 'D':
        efs->listaFiles(true);
        break;
      case 'x':
        efs->deleteFile(sParams[2]);
        break;
      case 'e':
        efs->execute(sParams[2].toInt());
        break;
      case 'n':
        efs->newFile(sParams[2]);
        break;
      case 't':
        efs->torra(sParams[2].toInt());
        break;
      case 'g':
        c->setGateMode(sParams[2].toInt());
        break;
      case 's':
        efs->cuntzToFile(c,sParams[2].toInt());
        break;
      case 'l':
        efs->cuntzFromFileJson(c,sParams[2].toInt(),true);
        break;
      /*case 'L':
        ldMancd.frequency(sParams[2].toInt());
        ldMancd.resonance(sParams[3].toFloat());
        mdMixer.gain(2,sParams[4].toFloat());  //TEST
        break;
        */
      case 'f':
        //efs->cuntzFromFileFunction(c,sParams[2].toInt(),false);
        efs->cuntzFromFile(c,sParams[2],false,'F');
        break;
      case 'r':
        efs->cuntzFromFileJson(c,sParams[2].toInt(),false);
        break;
      case 'h':
        resetController();
        break;
      case 'z':
        efs->readPrefs(c);
        break;
      case 'p':
        efs->savePrefs(c);
        break;
      case 'c':
        delay(500);
        initCuntz();
        break;
      case 'u':
        d->displayPage();
        d->update();
        break;
      case 'w':
        if (sParams[2].toInt()==0) {
          d->setEnabled(false);        
        } else {
          d->setEnabled(true);        
        }
        break;
      case 'v':   //reverb 
       {
        float d=sParams[2].toInt()/10;
        float r=sParams[3].toInt()/10;
        freeverbR.roomsize(r);
        freeverbR.damping(d);
        freeverbL.roomsize(r);
        freeverbL.damping(d);
       }
      break;
      case 'Y': //restore
        restore();
      break;
      case 'N':
        playNoda();
        break;
      case '?':
        com->msgInfo(info_E);
        break;
      case 'R':
         rec->parse(s); //Cuntzertu
        break;
      case 'P':   //Pedaliera 
      {
          uint8_t ped=sParams[2].toInt();
          switch (ped_mode) {
            case STRAC: {
              if (ped!=7) efs->cuntzFromFileJson(c,sParams[2].toInt()+ped_strac,true);   
               d->displayPage();
               d->update();            
            }
            break;
            case CROMA: {
              if (ped!=7) {
                c->setPuntu(c->getPuntu()-ped_last+ped);
                d->displayPage();
                d->update();
              }
            }
            break;
            case CONTROL: {
              if (ped!=7) {
                switch (ped) {
                  case 0: {
                  if (!efs->isMounted()) break;
                  do {
                    cuntz_num=(cuntz_num+1+MAX_CUNTZ_NUM)%MAX_CUNTZ_NUM;
                    } while (!efs->cuntzFromFileJson(c,cuntz_num,true));
                  }
                  break;
                  case 1: {
                  if (!efs->isMounted()) break;
                  do {
                    cuntz_num=(cuntz_num-1+MAX_CUNTZ_NUM)%MAX_CUNTZ_NUM;
                    } while (!efs->cuntzFromFileJson(c,cuntz_num,true));
                  }
                  break;
                  case 2:
                    c->setPuntu(c->getPuntu()+1);
                  break;
                  case 3:
                    c->setPuntu(c->getPuntu()-1);
                  break;
                  case 4:
                    c->setModal(c->getModal()+1);
                  break;
                  case 5:
                    c->setModal(c->getModal()-1);
                  break;
                  case 6:
                    efs->cuntzFromFileJson(c,cuntz_num,true);                 
                    break;               
                }     
              }          
                d->displayPage();
                d->update();
              
            }
            break;
           
            case TUMBU_F: {
              if (ped!=7) c->parse("T C0 p "+String(c->diatToCroma(ped,c->getModal()))+"\n");
            }
            break;
            case TUMBU_T: {
              if (ped==7) c->parse("T C0 p 0\n");
              else c->parse("T C0 p "+String(c->diatToCroma(ped+1,c->getModal()))+"\n");
            }
            break;
      }
       if (ped!=7) ped_last=ped;
      
      }
      break;
      case 'M':   //Modu pedaliera
         ped_mode=sParams[2].toInt();
         switch (ped_mode) {
          case CROMA:
            ped_last=3;
          break;
          case STRAC:
            ped_strac=cuntz_num;
          default:
            ped_last=0;
         }
         
        break;
      default:
        com->msgError(String("Unknown command: E ")+sParams[1][0]);
        break;
    }
  }
  //d->displayPage();
}

void initCuntz() {
  
  setCannas();
  efs->readPrefs(c);
  
  if (digitalRead(PIN_PULS_CANC)) {
    if (!efs->cuntzFromFileJson(c,c->getPreferredCuntz(),true)) {
       c->deserialize(json);
       c->sync();;
    } else {
      cuntz_num=c->getPreferredCuntz();
    }
  } else {
    c->deserialize(json);
    c->sync();
  }
  
  //c->setVerb(.1,.8,.1);

  c->tumbu.setMIDI(1,127,24+c->getPuntu(),0);
  c->mancs.setMIDI(2,127,24+c->getPuntu(),0);
  c->mancd.setMIDI(3,127,24+c->getPuntu(),0);

  c->tumbu.playCrai(0);
  c->mancs.playCrai(0);
  c->mancd.playCrai(0);

  c->beginTimer();
  
  playNoda();
  
  efs->execute(0);
  
  c->mute(true);
}
void setCannas() {
  c->setBiquads(&bqOutL, &bqOutR);
  c->setOutAmps(&ampL, &ampR);
  c->setReverbs(&freeverbL, &freeverbR);
  c->setCannaMixers(&lMixer, &rMixer);

  c->tumbu.setMixer(&tMixer);
  c->tumbu.setSynth(&tSynth);
  c->tumbu.setBiquads(&bqTumbuStat1, &bqTumbuStat2);

  c->mancs.setMixer(&msMixer);
  c->mancs.setSynth(&msSynth);
  c->mancs.setBiquads(&bqMancsStat, &bqMancsDinCrais,&bqMancsDinFin);

  c->mancd.setMixer(&mdMixer);
  c->mancd.setSynth(&mdSynth);
  c->mancd.setBiquads(&bqMancdStat, &bqMancdDinCrais,&bqMancdDinFin);
}

void playNoda() {
  int t=c->getGateMode();
  c->setGateMode(0);
  c->mute(false);
  delay(500);
  c->mancs.playCrai(4);
  c->mancd.playCrai(2);
  delay(100);
  c->mancd.playCrai(1);
  delay(900);
  c->mancs.playCrai(0);
  c->mancd.playCrai(0);
  delay(1000);
  c->mancs.playCrai(4);
  c->mancd.playCrai(4);
  c->setGateMode(t);
  com->msgOk("Noda");
}

void restore() {
    for (int i=0;i<16;i++) {
      efs->copy(220+i,i);
    }
    com->msgOk("Restored");
}

void resetController() {
  
  delay(100);
  digitalWrite(CS_CON,HIGH);
  delay(100);
  digitalWrite(CS_CON,LOW);
  delay(100);
}
void myProgramChange(byte channel, byte program) {
  com->msgInfo("MIDI> ",String(program));
  
  efs->cuntzFromFileJson(c,program,true);
  d->displayPage();
  d->update();

}

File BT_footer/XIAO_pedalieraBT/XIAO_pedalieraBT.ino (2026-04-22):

/**
 * A BLE client example that is rich in capabilities.
 * There is a lot new capabilities implemented.
 * author unknown
 * updated by chegewara
 */

#include "BLEDevice.h"
//#include "BLEScan.h"

// The remote service we wish to connect to.
//static BLEUUID serviceUUID("4fafc201-1fb5-459e-8fcc-c5c9c331914b");
// The characteristic of the remote service we are interested in.
static BLEUUID charUUID("0000ffe1-0000-1000-8000-00805f9b34fb");
static BLEUUID serviceUUID("0000ffe0-0000-1000-8000-00805f9b34fb");

static boolean doConnect = false;
static boolean connected = false;
static boolean doScan = false;
static BLERemoteCharacteristic *pRemoteCharacteristic;
static BLEAdvertisedDevice *myDevice;

#define LED D3

int count;
int ocrai=0;

static void notifyCallback(BLERemoteCharacteristic *pBLERemoteCharacteristic, uint8_t *pData, size_t length, bool isNotify) {
  Serial.print("Notify callback for characteristic ");
  Serial.print(pBLERemoteCharacteristic->getUUID().toString().c_str());
  Serial.print(" of data length ");
  Serial.println(length);
  Serial.print("data: ");
  Serial.write(pData, length);
  Serial.println();
}

int last_stato=7;

class MyClientCallback : public BLEClientCallbacks {
  void onConnect(BLEClient *pclient) {}

  void onDisconnect(BLEClient *pclient) {
    connected = false;
    Serial.println("onDisconnect");
  }
};

bool connectToServer() {
  Serial.print("Forming a connection to ");
  Serial.println(myDevice->getAddress().toString().c_str());

  BLEClient *pClient = BLEDevice::createClient();
  Serial.println(" - Created client");

  pClient->setClientCallbacks(new MyClientCallback());

  // Connect to the remove BLE Server.
  pClient->connect(myDevice);  // if you pass BLEAdvertisedDevice instead of address, it will be recognized type of peer device address (public or private)
  Serial.println(" - Connected to server");
  pClient->setMTU(517);  //set client to request maximum MTU from server (default is 23 otherwise)

  // Obtain a reference to the service we are after in the remote BLE server.
  BLERemoteService *pRemoteService = pClient->getService(serviceUUID);
  if (pRemoteService == nullptr) {
    Serial.print("Failed to find our service UUID: ");
    Serial.println(serviceUUID.toString().c_str());
    pClient->disconnect();
    return false;
  }
  Serial.println(" - Found our service");

  // Obtain a reference to the characteristic in the service of the remote BLE server.
  pRemoteCharacteristic = pRemoteService->getCharacteristic(charUUID);
  if (pRemoteCharacteristic == nullptr) {
    Serial.print("Failed to find our characteristic UUID: ");
    Serial.println(charUUID.toString().c_str());
    pClient->disconnect();
    return false;
  }
  Serial.println(" - Found our characteristic");

  // Read the value of the characteristic.
  if (pRemoteCharacteristic->canRead()) {
    String value = pRemoteCharacteristic->readValue();
    Serial.print("The characteristic value was: ");
    Serial.println(value.c_str());
  }

  if (pRemoteCharacteristic->canNotify()) {
    pRemoteCharacteristic->registerForNotify(notifyCallback);
  }

  connected = true;
  return true;
}
/**
 * Scan for BLE servers and find the first one that advertises the service we are looking for.
 */
class MyAdvertisedDeviceCallbacks : public BLEAdvertisedDeviceCallbacks {
  /**
   * Called for each advertising BLE server.
   */
  void onResult(BLEAdvertisedDevice advertisedDevice) {
    Serial.print("BLE Advertised Device found: ");
    Serial.println(advertisedDevice.toString().c_str());

    // We have found a device, let us now see if it contains the service we are looking for.
    if (advertisedDevice.haveServiceUUID() && advertisedDevice.isAdvertisingService(serviceUUID)) {

      BLEDevice::getScan()->stop();
      myDevice = new BLEAdvertisedDevice(advertisedDevice);
      doConnect = true;
      doScan = true;

    } 
  }  // onResult
};  // MyAdvertisedDeviceCallbacks

void setup() {
  Serial.begin(115200);
  delay(1000);
  Serial.println("Starting Arduino BLE Client application...");
  BLEDevice::init("");
  pinMode(LED,OUTPUT);
  delay(100);
  digitalWrite(LED,HIGH);
    delay(300);
    digitalWrite(LED,LOW);
    delay(300);

  // Retrieve a Scanner and set the callback we want to use to be informed when we
  // have detected a new device.  Specify that we want active scanning and start the
  // scan to run for 5 seconds.
  BLEScan *pBLEScan = BLEDevice::getScan();
  pBLEScan->setAdvertisedDeviceCallbacks(new MyAdvertisedDeviceCallbacks());
  pBLEScan->setInterval(1349);
  pBLEScan->setWindow(449);
  pBLEScan->setActiveScan(true);
  pBLEScan->start(5, false);

  digitalWrite(LED,HIGH);
}  // End of setup.

// This is the Arduino main loop function.
void loop() {

  // If the flag "doConnect" is true then we have scanned for and found the desired
  // BLE Server with which we wish to connect.  Now we connect to it.  Once we are
  // connected we set the connected flag to be true.
  if (doConnect == true) {
    if (connectToServer()) {
      Serial.println("We are now connected to the BLE Server.");
    } else {
      Serial.println("We have failed to connect to the server; there is nothing more we will do.");
    }
    doConnect = false;
  }

  // If we are connected to a peer BLE Server, update the characteristic each time we are reached
  // with the current time since boot.
  if (connected) {
    
    int c=tasto();
    if (c!=ocrai) {
       String cmd="E P "+String(c)+"\n";
      pRemoteCharacteristic->writeValue(cmd.c_str(), cmd.length());
      digitalWrite(LED,HIGH);
      delay(100);
      digitalWrite(LED,LOW);

    } else {
      count++;
      if (count>50) {
        digitalWrite(LED,HIGH);
        delay(100);
        digitalWrite(LED,LOW);
        count=0;
      }
    }
    ocrai=c;
   

  } else if (doScan) {
    Serial.println("scan");
    BLEDevice::getScan()->start(0);  // this is just example to start scan after disconnect, most likely there is better way to do it in arduino
    digitalWrite(LED,HIGH);
    delay(300);
    digitalWrite(LED,LOW);
    delay(300);
    digitalWrite(LED,HIGH);
    delay(300);
    digitalWrite(LED,LOW);
    delay(1000);
  } else {
    //Nessun dispositivo
    digitalWrite(LED,HIGH);
    delay(100);
    digitalWrite(LED,LOW);
    delay(100);
    digitalWrite(LED,HIGH);
    delay(100);
    digitalWrite(LED,LOW);
    delay(500);
  }
  delay(100);

  //delay(1000);  // Delay a second between loops.
}  // End of loop

int tasto() {
  /*
  0   620   1160   1980   2600   3170   3860   */
  int n=analogRead(A2);
  //Serial.println(n);
  if (n>4000) return 7;
  if (n>3500) return 6;
  if (n>2900) return 5;
  if (n>2300) return 4;
  if (n>1400) return 3;
  if (n>900) return 2;
  if (n>300) return 1;
  return 0;
}

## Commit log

2024-01-31 Create Teensy
2024-02-02 Teensy code
2024-02-15 added 3d files
    Revised
    [ElectroV3_2_1.sch, Ghiera_V0.2.stl, Gommini_pcb.stl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]
2024-02-22 Battery measure fixed
2026-02-01 Latentza switch
